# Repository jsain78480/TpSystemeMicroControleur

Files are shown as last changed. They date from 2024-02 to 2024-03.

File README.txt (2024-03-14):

# TpSystemeMicroControleur Hicham IDIR et Julien SAINT-LEGER
Ce GITHUB est utilisé pour un TP Systèmes à Microcontroleurs à l'ENSEA.
Il est réalisé en binôme sur 4 séance.
L'objectif de ce TP est de concevoir, assembler et tester une carte électronique contenant un microcontrôleur STM32.
KICAD sera utilisé.
Faire un filtre numérique simple pour prouver le bon fonctionnement de la carte.

Question 1.1.6 : Baud rate 115 200 Bits/s

Question 1.2.13 : PB9 est relié à la masse pour permettre le démarrage du STM32 depuis sa mémoire flash. Si PB9 était connecté à VDD alors le microcontroleur démarrerait en mode programmation. On peut retrouver ces informations dans la datasheet du STM32 ( 3.4.4 At startup, BOOT0 pin and nBOOT0, nBOOT1 and nBOOT_SEL option bits are used to select one of three boot options:• Boot from Flash memory• Boot from System memory• Boot from embedded RAM)

Question 1.2.14 : Les composants L1,C5 et C7 permettent de stabiliser l'alimentation  du STM32.

Question 1.3.3 : Page 3 sur 17 avec un minimum de 0,47 uF et maximum de 1uF (choix pris en conception)

Question 1.3.5 : Page 25 sur 49 où est indiqué que C1 = 10uF et C2 = 0,1uF

Question 1.3.6 : La broche CS/ permet au STM32 de sélectionner le DAC parmis tous les composants utilisés dans notre architecture. On peut voir sur STM32cubeMX que la sortie PA3 est utilisé en GPIO pour venir piloter cette broche. Lorsque CS/=0 alors le DAC est prêt à recevoir des données car il a été selectionné par le STM32.

Question 1.3.7 : Lorsque l'on n'utilise pas la broche LDAC/ alors on est en mode asynchrone, les valeurs analogiques sont placés instantanémment en sortie du DAC et transmis en DAC_OUT. Si on utilise la broche LDAC/ alors on est en mode synchrone, les valeurs analogiques sont placés en sortie du DAC lorsque l'on aura LDAC/=0

Question 1.3.8 : Le signal MISO n'est pas utilisé. Ce qui nous interesse dans notre application c'est la transmission de données du maitre vers l'esclave (STM32 vers le DAC) et non l'inverse. On utilisera dans notre projet le signal MOSI.

Question 1.3.10 : On peut retrouver ces indications dans la datasheet du STM32-V3MINI à la page 19/28

Question 1.4.3 : Par exemple dans 0805, 08 représente la longueur du composant et 05 la largeur du composant (0.08 pouces et 0.05 pouces). Les composants sont des composants CMS. Les empruntes permettent de garantir que les pads seront de la bonne dimension pour placer les composants.

Question 1.4.4 : Ils désignent tous des boitiers utilisés pour entourer les composants placés sur notre PCB. LQFP (Low-profile Quad Flat Package) signifie que c'est un boitier de faible hauteur pouvant couvrir des composants avec de nombreuses broches dissimulés sur les 4 extrémités du composants. SOT-223 est utilisé pour les régulateurs de tensions. A ce stade, nous pouvons penser qu'il sera utilisé pour notre régulateur BU33SD5WG-TR. SOIC est un boitier rectangulaire principalement utilisé pour des composants comme le DAC. A ce stade, nous pouvons penser qu'il sera utilisé pour notre DAC MCP4801-E/SN
test

Question 3.1.2 Utiliser des LL au lieu des HAL permet d'utiliser des registres de bas niveau pour avoir une meilleure optimisation. Les pilotes LL sont spécifiques au microp et les fonctions HAL sont plus portables.

Question 3.1.4 STATIC_INLINE est utilisé pour déclarer une fonction spécifique.

Question 3.1.5 Le compilateur va insérer les fonctions INLINE au besoin d'appel. C'est pour cette raison que du code est écrit dans ces dernières. Cela remplace un appel de fonction communémement réalisé en C.

Question 3.2.2 Nous avons une horloge de 16 Mhz, on aura donc un prescaler=63 sachant que notre Counter period (ARR)=255 pour avoir 1khz.

Question 3.3.3 Nous avons une horloge de 16 Mhz, on aura donc un prescaler=63 sachant que notre Counter period (ARR)=255 pour avoir 1khz.

Question 3.3.6 La routine du service d'interruption se situe dans le fichier stm32l0xx_it.c

Question 3.3.7 Les librairies LL sont beaucoup plus bas niveau et jouent sur les registres. Il est nécessaire de connaître le hardware pour les utiliser. Par soucis de mémoire interne au STM32,leur utilisation est rendu obligatoire pour ce TP. 
              
Question 3.3.8 Il faut gérer le flag dans l'interruption. Si ce n'est pas fait celà on peut boucler en continu dans l'interruption sans y sortir.

Question 3.3.9 Il faut mettre à 0 le flag à la fin de l'interruption. Dans notre cas; nous avons mis LL_TIM_ClearFlag_UPDATE(TIM21)

Question 3.4.5 Il manque le & devant ch dans SerialTransmit(ch,1)

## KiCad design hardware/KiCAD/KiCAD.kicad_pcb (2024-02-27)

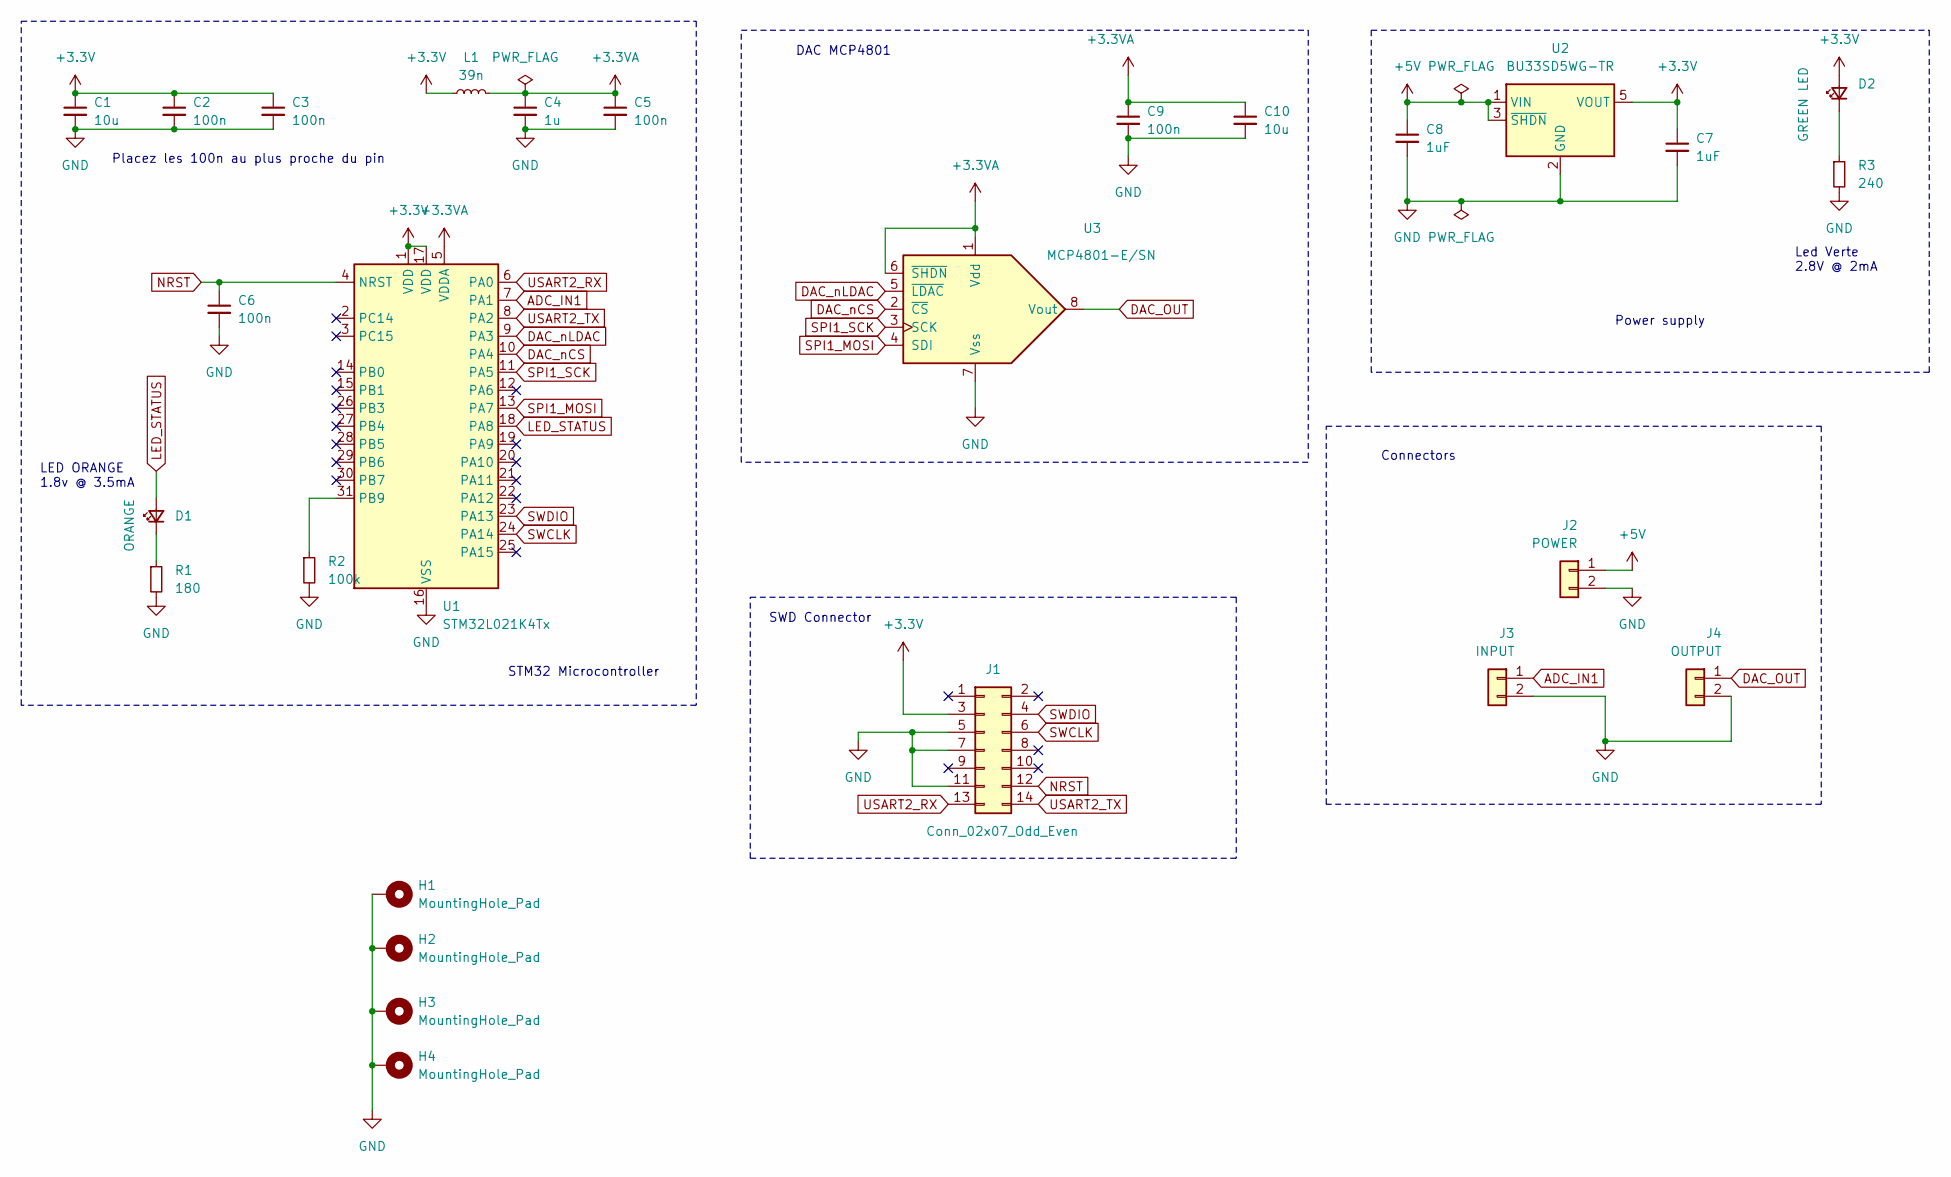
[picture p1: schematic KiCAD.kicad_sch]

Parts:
C1, C10: 10u; C_0805_2012Metric_Pad1.18x1.45mm_HandSolder
C2, C3, C5, C6, C9: 100n; C_0805_2012Metric_Pad1.18x1.45mm_HandSolder
C4: 1u; C_0805_2012Metric_Pad1.18x1.45mm_HandSolder
C7, C8: 1uF; C_0805_2012Metric_Pad1.18x1.45mm_HandSolder
D1: ORANGE; LED_0603_1608Metric_Pad1.05x0.95mm_HandSolder
D2: GREEN LED; LED_0603_1608Metric_Pad1.05x0.95mm_HandSolder; MPN 150060GS75000
H1, H2, H3, H4: MountingHole_Pad; MountingHole_3.2mm_M3_Pad
J1: Conn_02x07_Odd_Even; PinHeader_2x07_P1.27mm_Vertical_SMD
J2: POWER; JST_XH_B2B-XH-A_1x02_P2.50mm_Vertical
J3: INPUT; JST_XH_B2B-XH-A_1x02_P2.50mm_Vertical
J4: OUTPUT; JST_XH_B2B-XH-A_1x02_P2.50mm_Vertical
L1: 39n; L_0805_2012Metric_Pad1.05x1.20mm_HandSolder
R1: 180; R_0805_2012Metric_Pad1.20x1.40mm_HandSolder
R2: 100k; R_0805_2012Metric_Pad1.20x1.40mm_HandSolder
R3: 240; R_0805_2012Metric_Pad1.20x1.40mm_HandSolder
U1: STM32L021K4Tx; LQFP-32_7x7mm_P0.8mm
U2: BU33SD5WG-TR; SOT-23-5; MPN BU33SD5WG-TR
U3: MCP4801-E/SN; SOIC-8_3.9x4.9mm_P1.27mm; MPN MCP4801-E/SN

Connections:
+3.3V: C1.1, C2.1, C3.1, C7.1, D2.2 (A), J1.3, L1.1, U1.1 (VDD), U1.17 (VDD), U2.5 (VOUT)
+3.3VA: C4.1, C5.1, C9.1, C10.1, L1.2, U1.5 (VDDA), U3.1 (Vdd), U3.6 (~SHDN)
+5V: C8.1, J2.1, U2.1 (VIN), U2.3 (~SHDN)
ADC_IN1: J3.1, U1.7 (PA1)
DAC_OUT: J4.1, U3.8 (Vout)
DAC_nCS: U1.10 (PA4), U3.2 (~CS)
DAC_nLDAC: U1.9 (PA3), U3.5 (~LDAC)
GND: C1.2, C2.2, C3.2, C4.2, C5.2, C6.2, C7.2, C8.2, C9.2, C10.2, H1.1, H2.1, H3.1, H4.1, J1.5, J1.7, J1.11, J2.2, J3.2, J4.2, R1.2, R2.2, R3.2, U1.16 (VSS), U1.32 (VSS), U2.2 (GND), U3.7 (Vss)
LED_STATUS: D1.2 (A), U1.18 (PA8)
NRST: C6.1, J1.12, U1.4 (NRST)
unnamed: D1.1 (K), R1.1
unnamed: D2.1 (K), R3.1
unnamed: R2.1, U1.31 (PB9)
SPI1_MOSI: U1.13 (PA7), U3.4 (SDI)
SPI1_SCK: U1.11 (PA5), U3.3 (SCK)
SWCLK: J1.6, U1.24 (PA14)
SWDIO: J1.4, U1.23 (PA13)
USART2_RX: J1.13, U1.6 (PA0)
USART2_TX: J1.14, U1.8 (PA2)

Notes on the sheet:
Placez les 100n au plus proche du pin
Connectors
SWD Connector
LED ORANGE 1.8v @ 3.5mA
Led Verte 2.8V @ 2mA
DAC MCP4801
Power supply
STM32 Microcontroller

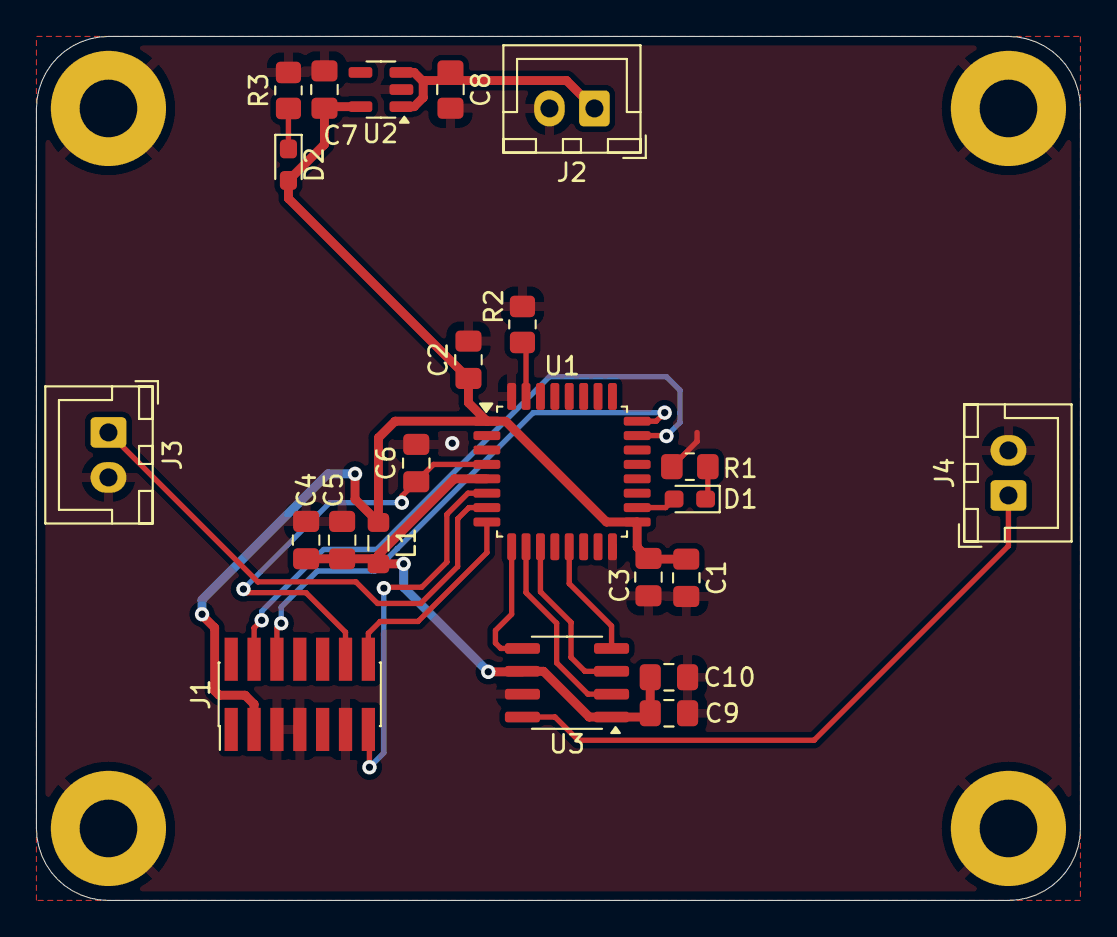
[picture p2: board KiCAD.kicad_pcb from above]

Board: 2 copper layers, 58.0 x 48.0 mm, 27 parts (0 on the bottom side), 19 nets.

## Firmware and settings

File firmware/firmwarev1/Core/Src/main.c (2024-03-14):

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
/* Includes ------------------------------------------------------------------*/
#include "main.h"
#include "adc.h"
#include "spi.h"
#include "tim.h"
#include "usart.h"
#include "gpio.h"

/* USER CODE BEGIN Includes */
#include "Shell.h"
#include "led.h"
#include "Timebase.h"
#include "Serial.h"
/* USER CODE END Includes */


/* USER CODE BEGIN PV */

hShell_t hShell;

/* USER CODE END PV */

void SystemClock_Config(void);
/* USER CODE BEGIN 0 */
extern int it_led;

/* USER CODE END 0 */

/**
  * @brief  The application entry point.
  * @retval int
  */
int main(void)
{
  /* MCU Configuration--------------------------------------------------------*/

  /* Reset of all peripherals, Initializes the Flash interface and the Systick. */
  HAL_Init();

  /* Configure the system clock */
  SystemClock_Config();

  /* Initialize all configured peripherals */
  MX_GPIO_Init();
  MX_USART2_UART_Init();
  MX_ADC_Init();
  MX_TIM2_Init();
  MX_TIM21_Init();
  MX_SPI1_Init();
  /* USER CODE BEGIN 2 */

  LedStart();
  ShellInit(&hShell, &SerialTransmit);
  LL_USART_EnableIT_RXNE(USART2);
  TimeBaseStartIT();

  /* USER CODE END 2 */

  /* Infinite loop */
  /* USER CODE BEGIN WHILE */
  while (1)
  {
	  //UART et SHELL
	  //char c = SerialReceiveByte();
	  //ShellProcess(&hShell, c);

	  // LED TIMER voir stm32l0xx_it_c

	  // LED SIMPLE
	  //LedPulse();
	  //LL_mDelay(10);

	  //UART SIMPLE ECHO
	  //char ch = SerialReceiveChar();
	  //SerialTransmit(&ch, 1);


    /* USER CODE END WHILE */

    /* USER CODE BEGIN 3 */
  }
  /* USER CODE END 3 */
}

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


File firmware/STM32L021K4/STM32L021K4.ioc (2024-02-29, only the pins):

Mcu.UserName=STM32L021K4Tx
PA0-CK_IN.Signal=USART2_RX
PA1.Signal=ADC_IN1
PA13.Signal=SYS_SWDIO
PA14.Signal=SYS_SWCLK
PA2.Signal=USART2_TX
PA3.GPIO_Label=DAC_nLDAC
PA3.Signal=GPIO_Analog
PA4.GPIO_Label=DAC_nCS
PA4.Signal=GPIO_Analog
PA5.Signal=SPI1_SCK
PA6.Signal=SPI1_MISO
PA7.Signal=SPI1_MOSI
PA8.Signal=S_TIM2_CH1

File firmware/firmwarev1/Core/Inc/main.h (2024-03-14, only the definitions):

#define DAC_nLDAC_Pin LL_GPIO_PIN_3
#define DAC_nLDAC_GPIO_Port GPIOA
#define DAC_nCS_Pin LL_GPIO_PIN_4
#define DAC_nCS_GPIO_Port GPIOA

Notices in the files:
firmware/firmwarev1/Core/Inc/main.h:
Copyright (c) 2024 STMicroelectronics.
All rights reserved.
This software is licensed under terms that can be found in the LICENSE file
